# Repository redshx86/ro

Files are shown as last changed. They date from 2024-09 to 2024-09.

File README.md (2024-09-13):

The control box i made for my reverse osmosis filter. I doubt anyone needs this.

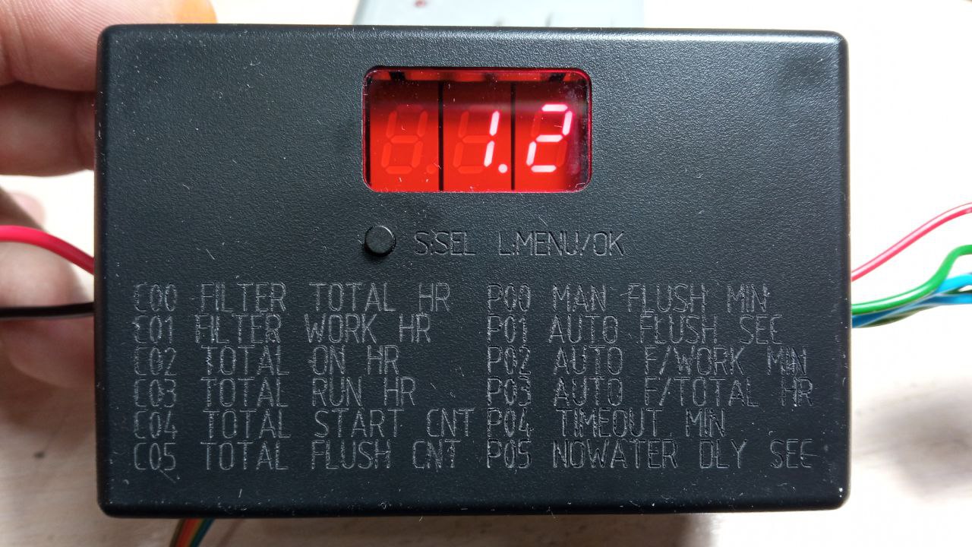
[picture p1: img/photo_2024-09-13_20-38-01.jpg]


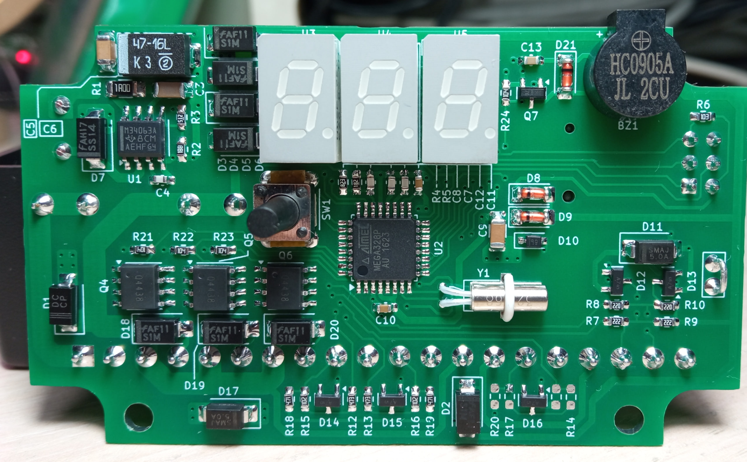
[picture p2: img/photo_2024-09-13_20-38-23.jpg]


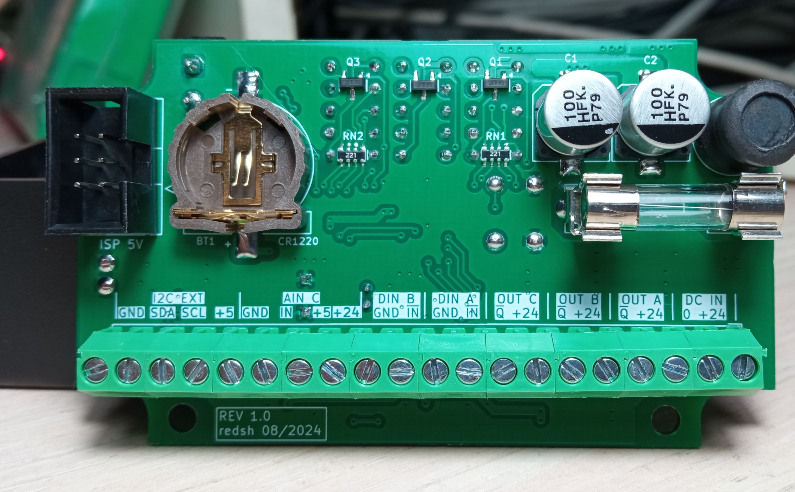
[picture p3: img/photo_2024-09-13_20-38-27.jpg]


## Main display
Off -> Blank\
Idle -> filter total time, days\
Work -> filtering time, minutes\
Flush -> Spin\
No water -> "drY"\
Timeout -> "Err"\
Short press: Off->on, Flush/Nowater/Timeout->idle, Other->lamp on/off\
Long press: menu\

### Menu
OFF -> Turn off\
FLU -> Start manual flush\
C00 -> Filter total time, hrs/thousands\
C01 -> Filter work time, hrs/thousands\
C02 -> Total on time, hrs/thousands\
C03 -> Total run time, hrs/thousands\
C04 -> Total start count, pcs/thousands\
C05 -> Total flush count, pcs/thousands\
P00 -> Manual flushing time 0..60/1 min\
P01 -> Auto flushing time 0..900/10 sec\
P02 -> Work time flush threshold 0..990/10 min\
P03 -> Total time flush threshold 0..240/5 hr\
P04 -> Timeout 0..360/5 min\
P05 -> Nowater delay 0..60/1 sec\
P06 -> Extra work time after HP switch off 0..360/5 sec\
CLr -> Reset filter on time/work time (confirm yes/no)\
X.XX -> AIN_C voltage (ok=back)\
XX.X -> Input voltage (ok=back)\
Long press: edit parameter/ok\
Short press: next parameter\

### Parameter edit / confirm menu\
short press: increase value / toggle confirm\
long press: save\

### Parameter display\
short press: back to menu\
long press: back to main display\

## Board pinout
DIA -> low pressure switch\
DIB -> high pressure switch\
DQA -> pump + inlet valve\
DQB -> flush valve\
DQC -> lamp\

## ATmega328 fuses
int.RC 8MHz 0ms+6CK DIV8\
BOR@1.8V

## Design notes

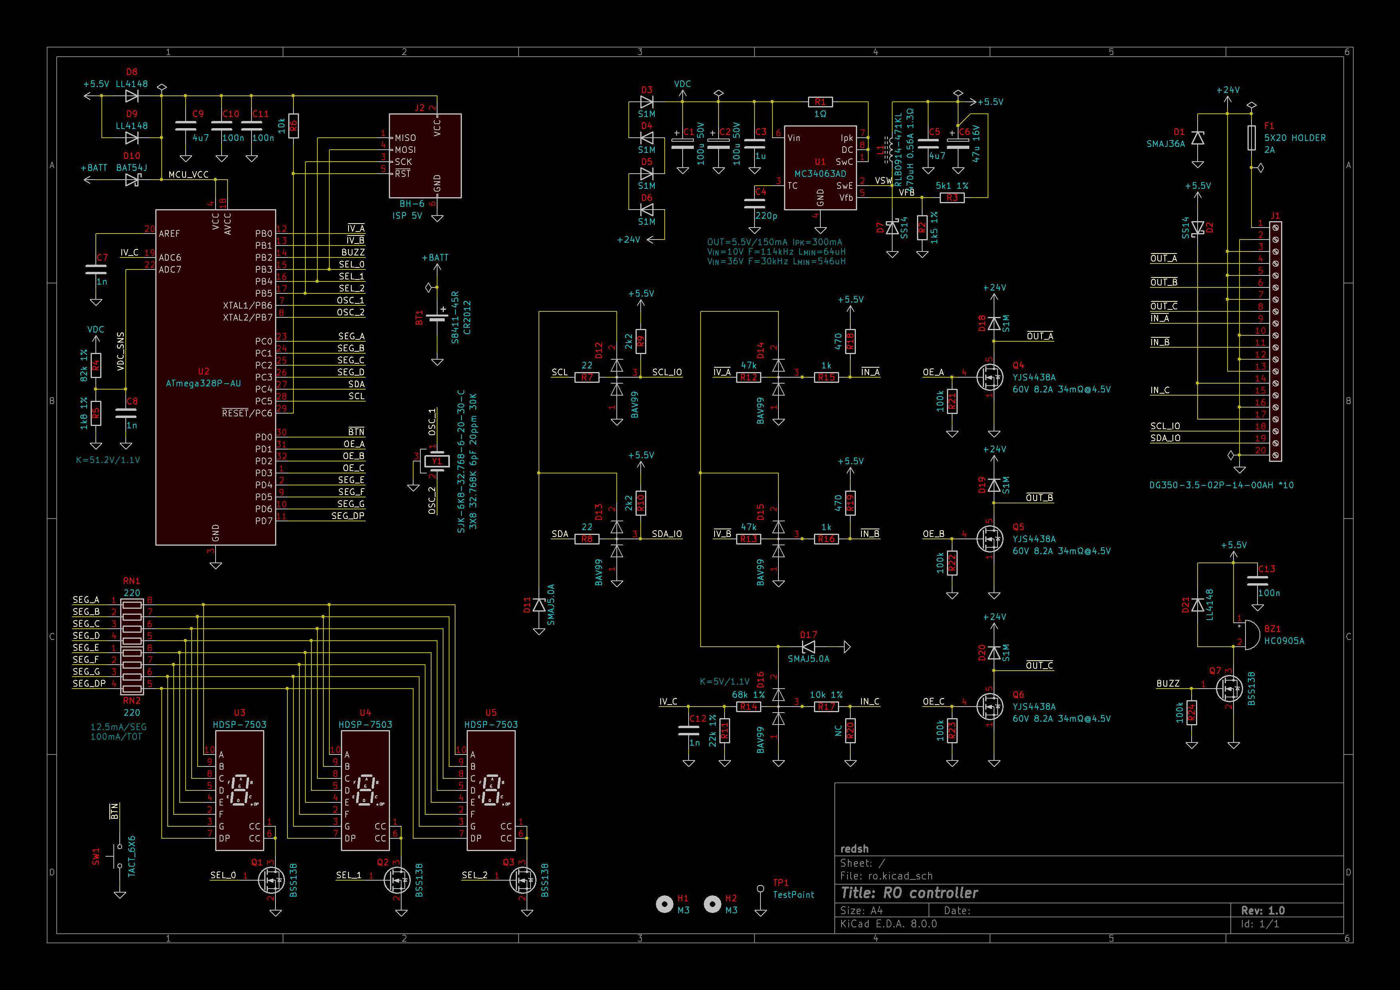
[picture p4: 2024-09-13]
img/sch.png

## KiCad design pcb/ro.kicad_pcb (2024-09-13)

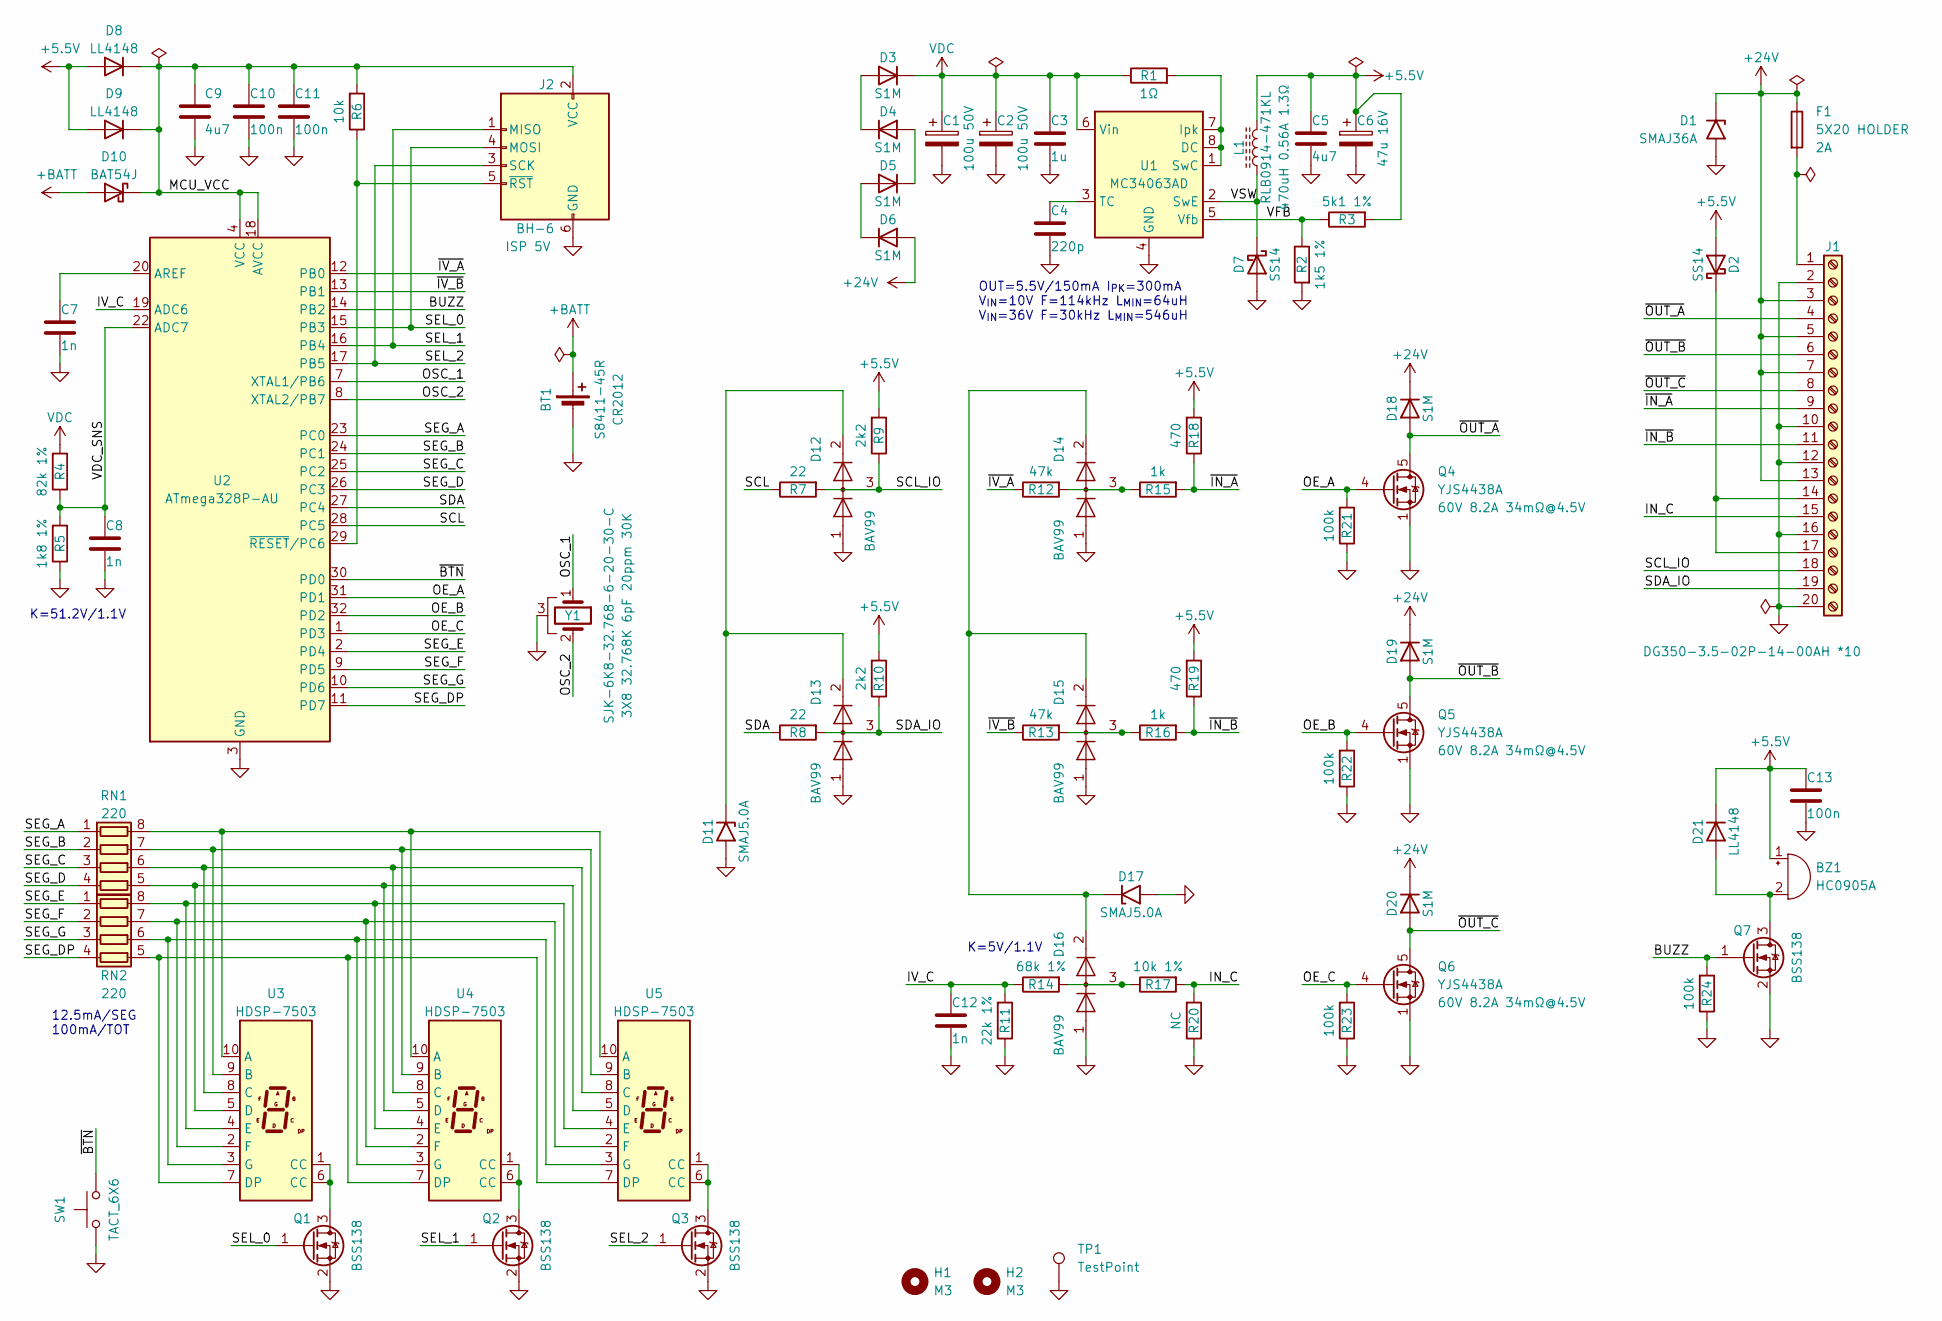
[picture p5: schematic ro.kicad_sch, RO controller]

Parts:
BT1: S8411-45R
BZ1: HC0905A; MagneticBuzzer_CUI_CST-931RP-A
C1, C2: 100u 50V; CP_Elec_8x10.5
C3: 1u; C_1206_3216Metric_Pad1.33x1.80mm_HandSolder
C4: 220p; C_0603_1608Metric_Pad1.08x0.95mm_HandSolder
C5, C9: 4u7; C_1206_3216Metric_Pad1.33x1.80mm_HandSolder
C6: 47u 16V; CP_EIA-7343-31_Kemet-D_Pad2.25x2.55mm_HandSolder
C7, C8, C12: 1n; C_0603_1608Metric_Pad1.08x0.95mm_HandSolder
C10, C11, C13: 100n; C_0603_1608Metric_Pad1.08x0.95mm_HandSolder
D1: SMAJ36A; D_SMA
D2, D7: SS14; D_SMA
D3, D4, D5, D6, D18, D19, D20: S1M; D_SMA
D8, D9, D21: LL4148; D_MiniMELF
D10: BAT54J; D_SOD-323_HandSoldering
D11, D17: SMAJ5.0A; D_SMA
D12, D13, D14, D15, D16: BAV99; SOT-23
F1: 5X20 HOLDER; Fuse_Clip_TE_520
H1, H2: M3; MountingHole_3.2mm_M3
J1: DG350-3.5-02P-14-00AH *10; TerminalBlock_4Ucon_1x20_P3.50mm_Horizontal
J2: BH-6; IDC-Header_2x03_P2.54mm_Vertical
L1: RLB0914-471KL; L_Radial_D8.7mm_P5.00mm_Fastron_07HCP
Q1, Q2, Q3, Q7: BSS138; SOT-23
Q4, Q5, Q6: YJS4438A; SOIC-8_3.9x4.9mm_P1.27mm
R1: 1Ω; R_1206_3216Metric_Pad1.30x1.75mm_HandSolder
R2: 1k5 1%; R_0603_1608Metric_Pad0.98x0.95mm_HandSolder
R3: 5k1 1%; R_0603_1608Metric_Pad0.98x0.95mm_HandSolder
R4: 82k 1%; R_0603_1608Metric_Pad0.98x0.95mm_HandSolder
R5: 1k8 1%; R_0603_1608Metric_Pad0.98x0.95mm_HandSolder
R6: 10k; R_0603_1608Metric_Pad0.98x0.95mm_HandSolder
R7, R8: 22; R_0603_1608Metric_Pad0.98x0.95mm_HandSolder
R9, R10: 2k2; R_0603_1608Metric_Pad0.98x0.95mm_HandSolder
R11: 22k 1%; R_0603_1608Metric_Pad0.98x0.95mm_HandSolder
R12, R13: 47k; R_0603_1608Metric_Pad0.98x0.95mm_HandSolder
R14: 68k 1%; R_0603_1608Metric_Pad0.98x0.95mm_HandSolder
R15, R16: 1k; R_0603_1608Metric_Pad0.98x0.95mm_HandSolder
R17: 10k 1%; R_0603_1608Metric_Pad0.98x0.95mm_HandSolder
R18, R19: 470; R_0603_1608Metric_Pad0.98x0.95mm_HandSolder
R20: NC; R_0603_1608Metric_Pad0.98x0.95mm_HandSolder
R21, R22, R23, R24: 100k; R_0603_1608Metric_Pad0.98x0.95mm_HandSolder
RN1, RN2: 220; R_Array_Convex_4x0603
SW1: TACT_6X6; SW_PUSH_6mm_H8mm
TP1: TestPoint; TestPoint_Bridge_Pitch2.54mm_Drill1.0mm
U1: MC34063AD; SOIC-8_3.9x4.9mm_P1.27mm
U2: ATmega328P-AU; TQFP-32_7x7mm_P0.8mm
U3, U4, U5: HDSP-7503; HDSP-A151
Y1: SJK-6K8-32.768-6-20-30-C; Crystal_C38-LF_D3.0mm_L8.0mm_Horizontal_1EP_style2

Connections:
+5.5V: BZ1.1 (+), C5.1, C6.1, C13.1, D2.2 (A), D8.2 (A), D9.2 (A), D21.1 (K), L1.1, R3.2, R9.2, R10.2, R18.2, R19.2
+24V: D1.1 (A1), D6.2 (A), D18.1 (K), D19.1 (K), D20.1 (K), F1.1, J1.3, J1.5, J1.7, J1.13
+BATT: BT1.1 (+), D10.2 (A)
/BUZZ: Q7.1 (G), R24.2, U2.14 (PB2)
/IN_C: J1.15, R17.2, R20.2
/IV_C: C12.1, R11.2, R14.1, U2.19 (ADC6)
/MCU_VCC: C9.1, C10.1, C11.1, D8.1 (K), D9.1 (K), D10.1 (K), J2.2 (VCC), R6.2, U2.4 (VCC), U2.6 (VCC), U2.18 (AVCC)
/OE_A: Q4.4 (G), R21.2, U2.31 (PD1)
/OE_B: Q5.4 (G), R22.2, U2.32 (PD2)
/OE_C: Q6.4 (G), R23.2, U2.1 (PD3)
/OSC_1: U2.7 (XTAL1/PB6), Y1.1
/OSC_2: U2.8 (XTAL2/PB7), Y1.2
/SCL: R7.1, U2.28 (PC5)
/SCL_IO: D12.3 (K), J1.18, R7.2, R9.1
/SDA: R8.1, U2.27 (PC4)
/SDA_IO: D13.3 (K), J1.19, R8.2, R10.1
/SEG_A: RN1.1 (R1.1), U2.23 (PC0)
/SEG_B: RN1.2 (R2.1), U2.24 (PC1)
/SEG_C: RN1.3 (R3.1), U2.25 (PC2)
/SEG_D: RN1.4 (R4.1), U2.26 (PC3)
/SEG_DP: RN2.4 (R4.1), U2.11 (PD7)
/SEG_E: RN2.1 (R1.1), U2.2 (PD4)
/SEG_F: RN2.2 (R2.1), U2.9 (PD5)
/SEG_G: RN2.3 (R3.1), U2.10 (PD6)
/SEL_0: J2.4 (MOSI), Q1.1 (G), U2.15 (PB3)
/SEL_1: J2.1 (MISO), Q2.1 (G), U2.16 (PB4)
/SEL_2: J2.3 (SCK), Q3.1 (G), U2.17 (PB5)
/VDC_SNS: C8.1, R4.1, R5.2, U2.22 (ADC7)
/VFB: R2.1, R3.1, U1.5 (Vfb)
/VSW: D7.1 (K), L1.2, U1.2 (SwE)
/~BTN: SW1.2, U2.30 (PD0)
/~IN_A: J1.9, R15.2, R18.1
/~IN_B: J1.11, R16.2, R19.1
/~IV_A: R12.1, U2.12 (PB0)
/~IV_B: R13.1, U2.13 (PB1)
/~OUT_A: D18.2 (A), J1.4, Q4.5 (D), Q4.6 (D), Q4.7 (D), Q4.8 (D)
/~OUT_B: D19.2 (A), J1.6, Q5.5 (D), Q5.6 (D), Q5.7 (D), Q5.8 (D)
/~OUT_C: D20.2 (A), J1.8, Q6.5 (D), Q6.6 (D), Q6.7 (D), Q6.8 (D)
GND: BT1.2 (-), C1.2, C2.2, C3.2, C4.2, C5.2, C6.2, C7.2, C8.2, C9.2, C10.2, C11.2, C12.2, C13.2, D1.2 (A2), D7.2 (A), D11.2 (A2), D12.1 (K), D13.1 (K), D14.1 (K), D15.1 (K), D16.1 (K), D17.2 (A2), J1.2, J1.10, J1.12, J1.16, J1.20, J2.6 (GND), Q1.2 (S), Q2.2 (S), Q3.2 (S), Q4.1 (S), Q4.2 (S), Q4.3 (S), Q5.1 (S), Q5.2 (S), Q5.3 (S), Q6.1 (S), Q6.2 (S), Q6.3 (S), Q7.2 (S), R2.2, R5.1, R11.1, R20.1, R21.1, R22.1, R23.1, R24.1, SW1.1, TP1.1, U1.4 (GND), U2.3 (GND), U2.5 (GND), U2.21 (GND), Y1.3
unnamed: BZ1.2 (-), D21.2 (A), Q7.3 (D)
unnamed: D2.1 (K), J1.14, J1.17
unnamed: D3.2 (A), D4.1 (K)
unnamed: D4.2 (A), D5.1 (K)
unnamed: D5.2 (A), D6.1 (K)
unnamed: D11.1 (A1), D12.2 (A), D13.2 (A)
unnamed: D14.2 (A), D15.2 (A), D16.2 (A), D17.1 (A1)
unnamed: D14.3 (K), R12.2, R15.1
unnamed: D15.3 (K), R13.2, R16.1
unnamed: D16.3 (K), R14.2, R17.1
unnamed: F1.2, J1.1
unnamed: J2.5 (~RST), R6.1, U2.29 (~RESET/PC6)
unnamed: Q1.3 (D), U3.1 (CC), U3.6 (CC)
unnamed: Q2.3 (D), U4.1 (CC), U4.6 (CC)
unnamed: Q3.3 (D), U5.1 (CC), U5.6 (CC)
unnamed: RN1.8 (R1.2), U3.10 (A), U4.10 (A), U5.10 (A)
unnamed: RN1.7 (R2.2), U3.9 (B), U4.9 (B), U5.9 (B)
unnamed: RN1.6 (R3.2), U3.8 (C), U4.8 (C), U5.8 (C)
unnamed: RN1.5 (R4.2), U3.5 (D), U4.5 (D), U5.5 (D)
unnamed: RN2.8 (R1.2), U3.4 (E), U4.4 (E), U5.4 (E)
unnamed: RN2.7 (R2.2), U3.2 (F), U4.2 (F), U5.2 (F)
unnamed: RN2.6 (R3.2), U3.3 (G), U4.3 (G), U5.3 (G)
unnamed: RN2.5 (R4.2), U3.7 (DP), U4.7 (DP), U5.7 (DP)
unnamed: R1.2, U1.1 (SwC), U1.7 (Ipk), U1.8 (DC)
unnamed: C4.1, U1.3 (TC)
unnamed: C7.1, U2.20 (AREF)
VDC: C1.1, C2.1, C3.1, D3.1 (K), R1.1, R4.2, U1.6 (Vin)

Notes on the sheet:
K=5V/1.1V
OUT=5.5V/150mA I_{PK}=300mA V_{IN}=10V F=114kHz L_{MIN}=64uH V_{IN}=36V F=30kHz L_{MIN}=546uH
12.5mA/SEG 100mA/TOT
K=51.2V/1.1V

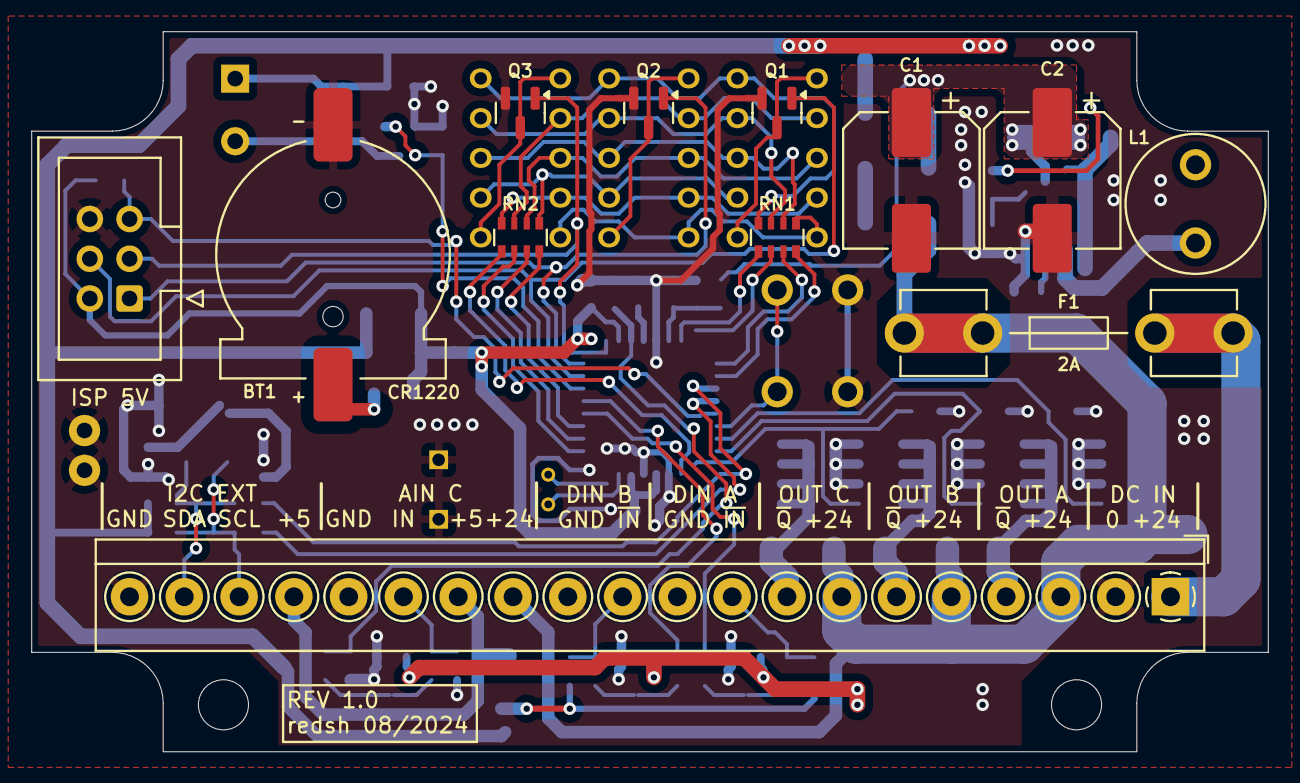
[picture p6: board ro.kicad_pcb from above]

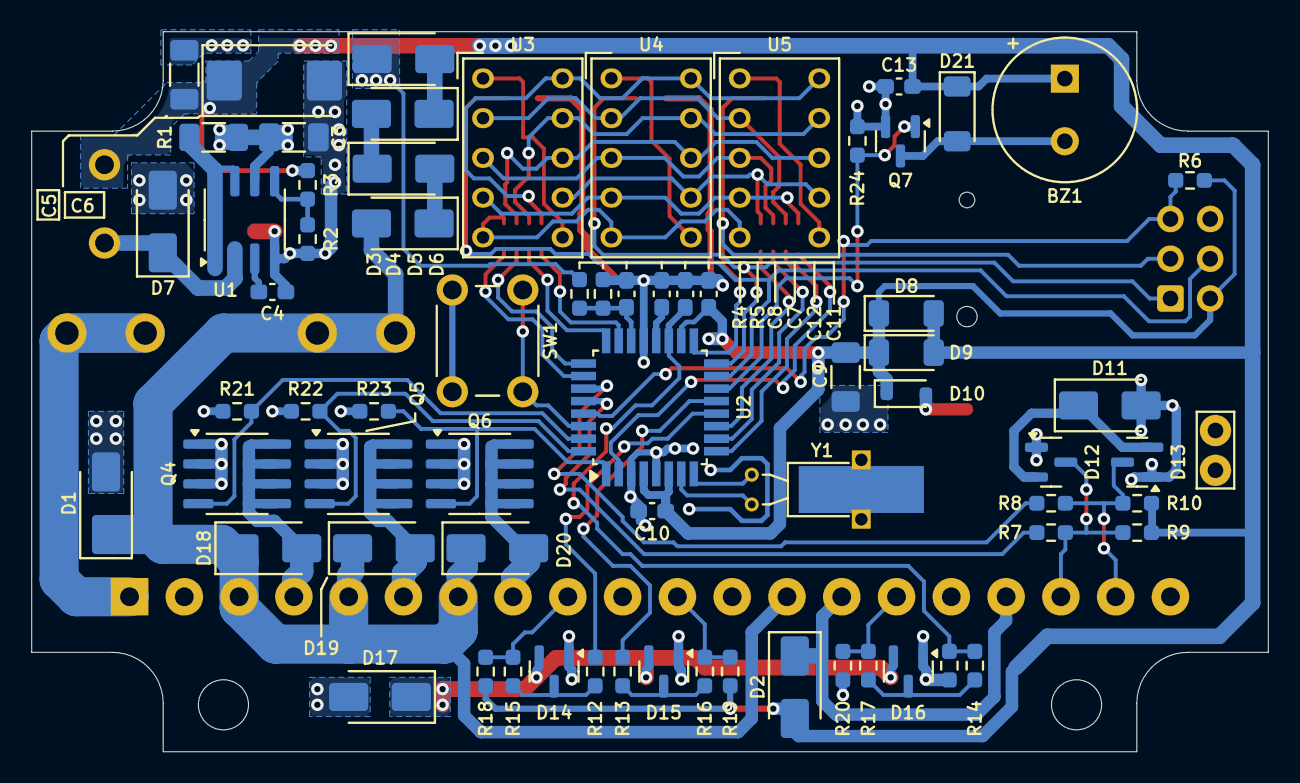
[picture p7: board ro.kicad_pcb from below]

Board: 2 copper layers, 79.0 x 46.0 mm, 83 parts (71 on the bottom side), 66 nets.

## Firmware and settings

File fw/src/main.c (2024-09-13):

//--------------------------------------------------------------------------------------------------

#include <avr/io.h>
#include <avr/wdt.h>
#include <avr/power.h>
#include <avr/sleep.h>
#include <avr/interrupt.h>
#include "lib/os/os.h"
#include "lib/adc.h"
#include "lib/rtc.h"
#include "ro.h"
#include "menu.h"
#include "config.h"
#include "hwconf.h"

//--------------------------------------------------------------------------------------------------
// PWR

static void adc_callback(const uint16_t *res);
static uint8_t is_pwr_on;

static void pwr_on()
{
	TICK_DISP_ENABLE();					// enable display and system tick
	adc_read_enable(adc_callback);		// enable ADC refresh
	menu_enable();						// enable ui
	ro_enable();						// enable RO controller

	// power on mode
	set_sleep_mode(SLEEP_MODE_IDLE);
	is_pwr_on = 1;
}

static void pwr_off()
{
	ro_disable();						// disable RO controller
	menu_disable();						// disable ui
	adc_read_disable();					// disable ADC refresh
	TICK_DISP_DISABLE();				// disable display and system tick

	// power save mode
	set_sleep_mode(SLEEP_MODE_PWR_SAVE);
	is_pwr_on = 0;
}

//--------------------------------------------------------------------------------------------------
// ADC callback. 5-sample average: 0..(1024*5)

uint16_t ain_c;
uint16_t vin;

static void adc_callback(const uint16_t *res)
{
	ain_c = (uint16_t) (res[ADC_AIN_C] * 1000UL >> 10);	// 1024*5 -> 5000mV FS
	vin = res[ADC_VDC] * 10 + VIN_DROP;					// 1024*5 -> 51200mV FS + VDC diode drop

	// pwr off mode by the input voltage threshold
	if(vin < VIN_THRES_PWRDOWN)
		pwr_off();
}

//--------------------------------------------------------------------------------------------------
// RTC tick (2s)

static void rtc_tick(struct task_handle *task)
{
	// wake up by the input voltage threshold
	// 1024->51.2V FS + VDC diode drop
	if(!is_pwr_on && (adc_read_single(ADMUX_VDC) >= (VIN_THRES_PWRUP-VIN_DROP)/50))
		pwr_on();
	// update rtc second counter
	t_rtc_sec += 2;
}

static void rtc_init()
{
	static struct task_handle rtc_tick_task = TASK_HANDLE(rtc_tick);
	RTC_TICK_INIT();
	task_flag_bind(RTC_TICK_FLAG_ID, &rtc_tick_task, TASK_PRIORITY_NORMAL);
}

//--------------------------------------------------------------------------------------------------

static void mcu_init()
{
	// initialize MCU
	MCUSR = 0;
	wdt_disable();
	clock_prescale_set(clock_div_2); // F_CPU=4MHz
	set_sleep_mode(SLEEP_MODE_PWR_SAVE);

	// initialize GPIO
//	PORTB = PORTB_INIT;
	DDRB = DDRB_INIT;
//	PORTC = PORTC_INIT;
	DDRC = DDRC_INIT;
//	PORTD = PORTD_INIT;
	DDRD = DDRD_INIT;

	ACSR = 1<<ACD;
	PRR = (1<<PRTWI)|(1<<PRSPI)|(1<<PRUSART0)|(1<<PRTIM0)|(1<<PRTIM1);

	sei();
}

int main()
{
	mcu_init();
	os_init();
	rtc_init();
	ro_load_ee();
	os_run();
}

//--------------------------------------------------------------------------------------------------

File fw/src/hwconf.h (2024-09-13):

// -------------------------------------------------------------------------------------------------
// RO controller MCU pinout

#pragma once

// -------------------------------------------------------------------------------------------------
// Discrete input

#define DI_PIN				PINB
#define DI_A_N				(1<<PB0)
#define DI_B_N				(1<<PB1)

#define DI_A_IS_ON()		!(DI_PIN & DI_A_N)
#define DI_B_IS_ON()		!(DI_PIN & DI_B_N)

// -------------------------------------------------------------------------------------------------
// Discrete output

#define DQ_PORT				PORTD
#define DQ_PIN				PIND
#define DQ_A_P				(1<<PD1)
#define DQ_B_P				(1<<PD2)
#define DQ_C_P				(1<<PD3)

#define DQ_A_ON()			DQ_PORT |= DQ_A_P
#define DQ_A_OFF()			DQ_PORT &= ~DQ_A_P
#define DQ_A_TGL()			DQ_PIN = DQ_A_P
#define DQ_A_IS_ON()		(DQ_PORT & DQ_A_P)

#define DQ_B_ON()			DQ_PORT |= DQ_B_P
#define DQ_B_OFF()			DQ_PORT &= ~DQ_B_P
#define DQ_B_TGL()			DQ_PIN = DQ_B_P
#define DQ_B_IS_ON()		(DQ_PORT & DQ_B_P)

#define DQ_C_ON()			DQ_PORT |= DQ_C_P
#define DQ_C_OFF()			DQ_PORT &= ~DQ_C_P
#define DQ_C_TGL()			DQ_PIN = DQ_C_P
#define DQ_C_IS_ON()		(DQ_PORT & DQ_C_P)

// -------------------------------------------------------------------------------------------------
// 7-segment display

#define SEG_3_0_PORT		PORTC	// PORTC[3:0]=SEG[3:0]
#define SEG_7_4_PORT		PORTD	// PORTD[7:4]=SEG[7:4]
#define SEG_3_0_P			0x0F
#define SEG_7_4_P			0xF0

#define SEL_PORT			PORTB
#define SEL_0_BIT			PB3
#define SEL_1_BIT			PB4
#define SEL_2_BIT			PB5
#define SEL_0_P				(1<<SEL_0_BIT)
#define SEL_1_P				(1<<SEL_1_BIT)
#define SEL_2_P				(1<<SEL_2_BIT)
#define SEL_ALL				(SEL_0_P|SEL_1_P|SEL_2_P)

#define SEG_WRITE(data) do {												\
		SEG_3_0_PORT = (SEG_3_0_PORT & ~SEG_3_0_P) | ((data) & SEG_3_0_P);	\
		SEG_7_4_PORT = (SEG_7_4_PORT & ~SEG_7_4_P) | ((data) & SEG_7_4_P);	\
	} while(0)

#define SEL_OFF()			SEL_PORT &= ~(SEL_0_P|SEL_1_P|SEL_2_P)
#define SEL_0_ON()			SEL_PORT |= SEL_0_P
#define SEL_1_ON()			SEL_PORT |= SEL_1_P
#define SEL_2_ON()			SEL_PORT |= SEL_2_P

// -------------------------------------------------------------------------------------------------
// Push button

#define BTN_PIN				PIND
#define BTN_PORT			PORTD
#define BTN_DDR				DDRD
#define BTN_N				(1<<PD0)

#define BTN_ENABLE() do {		\
		BTN_DDR &= ~BTN_N;		\
		BTN_PORT |= BTN_N;		\
	} while(0)
#define BTN_DISABLE() do {		\
		BTN_PORT &= ~BTN_N;		\
		BTN_DDR |= BTN_N;		\
	} while(0)
#define BTN_IS_PSH()		!(BTN_PIN & BTN_N)

// -------------------------------------------------------------------------------------------------
// Buzzer (3.2kHz)

#define BUZZ_FREQ			3200
#define BUZZ_P				(1<<PB2)	// OC1B

#define BUZZ_ON()			TCCR1A |= 1<<COM1B1
#define BUZZ_OFF()			TCCR1A &= ~(1<<COM1B1)
#define BUZZ_IS_ON()		(TCCR1A & (1<<COM1B1))

// Timer1:FastPWM(TOP=OCR1A) @ F_CPU
// OC1B -> Buzzer
#define BUZZ_ENABLE() do {							\
		PRR &= ~(1<<PRTIM1);						\
		OCR1A = F_CPU/BUZZ_FREQ-1;					\
		OCR1B = F_CPU/BUZZ_FREQ/2;					\
		TCCR1A = (1<<WGM11)|(1<<WGM10);				\
		TCCR1B = (1<<WGM13)|(1<<WGM12)|(1<<CS10);	\
	} while(0)
#define BUZZ_DISABLE() do {							\
		BUZZ_OFF();									\
		TCCR1B &= ~(1<<CS10);						\
		PRR |= 1<<PRTIM1;							\
	} while(0)

// -------------------------------------------------------------------------------------------------

// Timer0:Normal @ F_CPU/64
// OC0A -> Sys tick and Display
#define TICK_DISP_ENABLE() do {						\
		PRR &= ~(1<<PRTIM0);						\
		TCCR0B = (1<<CS01)|(1<<CS00);				\
		TIMSK0 = 1<<OCIE0A;							\
	} while(0)
#define TICK_DISP_DISABLE() do {					\
		TCCR0B = 0;									\
		PRR |= 1<<PRTIM0;							\
		SEG_WRITE(0);								\
		SEL_OFF();									\
	} while(0)

// -------------------------------------------------------------------------------------------------

// Timer2:Async @ F_32K/256
// OVF -> RTC tick
#define RTC_TICK_INIT() do {						\
		ASSR = 1<<AS2;								\
		TCNT2 = 0;									\
		OCR2A = 0;									\
		OCR2B = 0;									\
		TCCR2A = 0;									\
		TCCR2B = (1<<CS22)|(1<<CS21);				\
		while(ASSR & 0x1f)							\
			;										\
		TIMSK2 = 1<<TOIE2;							\
	} while(0)

// -------------------------------------------------------------------------------------------------
// ADC

#define ADMUX_AIN_C			((1<<REFS1)|(1<<REFS0)|6)	// 5.00V FS
#define ADMUX_VDC			((1<<REFS1)|(1<<REFS0)|7)	// 51.2V FS

// -------------------------------------------------------------------------------------------------

//#define PORTB_INIT		(0)
#define DDRB_INIT			(BUZZ_P|SEL_0_P|SEL_1_P|SEL_2_P)
//#define PORTC_INIT		(0)
#define DDRC_INIT			(SEG_3_0_P)
//#define PORTD_INIT		(0)
#define DDRD_INIT			(BTN_N|DQ_A_P|DQ_B_P|DQ_C_P|SEG_7_4_P)

// -------------------------------------------------------------------------------------------------
